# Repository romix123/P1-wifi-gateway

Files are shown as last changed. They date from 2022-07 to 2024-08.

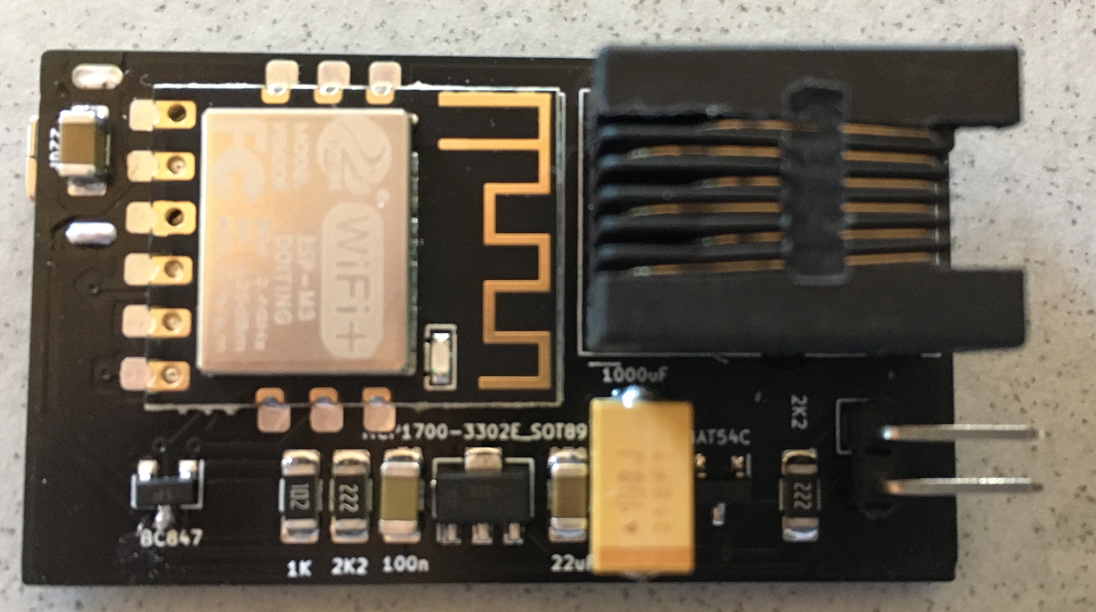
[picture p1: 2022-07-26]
hardware/P1-2022v2top.jpg

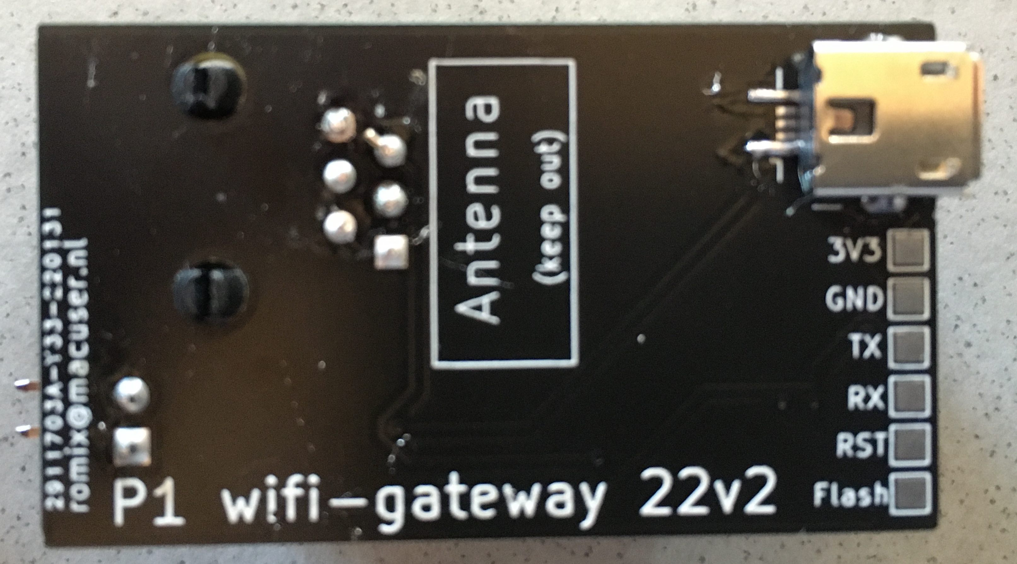
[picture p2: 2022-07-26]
hardware/P1-2022v2bot.jpg

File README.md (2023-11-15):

  P1 wifi gateway 2022
  
  Deze software brengt verschillende componenten bij elkaar in een handzaam pakket.
  
  De software draait op een ESP8285 of ESP8266 en heeft een bescheiden voetafdruk.
  
  De data processing is gebaseerd op: http://domoticx.com/p1-poort-slimme-meter-data-naar-domoticz-esp8266/
  De captive portal is gebaseerd op een van de ESP8266 voorbeelden, de OTA eenheid eveneens.
  
  De module levert data aan een host via JSON of MQTT messages, maar kan ook via de webinterface van de module of via telnet worden uitgelezen
  
  De module zal bij opstarten eerst de buffercondensator laden. 
  Vervolgens knippert hij 2x en zal eerst proberen te koppelen aan je wifi netwerk. Gedurende dat proces zal de LED knipperen
  met een periode van 0.5 Hz.
  Wanneer geen verbinding kan worden gemaakt start de modiule een Access point onder de naam P1_Setup
  Verbind met dit netwerk en surf naar 192.168.4.1
  
  Het menuscherm van de module verschijnt dan. Vul daar SSID en wachtwoord van je wifi netwerk in. 
  Daaronder vul je gegevens van de ontvangede server in (IP en poortnummer). Dit kan je DOmotociz server zijn
  In dat geval moet je ook het IDx dat Domoticz maakt voor een Gas device en een Energy device invoeren.
  Tenslotte geef je aan per hoeveel seconde je data naar de server wilt laten sturen.
  DSMR4 meters hanteren een meetinterval van 10 sec. SMR5 meters leveren iedere seconde data. Dat lijkt me wat veel en 
  kost de module ook veel stroom waardoor het maar de vraag is of hij parasitair (door de meter gevoed) kan werken.
  Ik raad een interval van 15 sec of hoger aan. Het interval dat je hier invoert zal niet altijd synchroon lopen met
  het data interval van de meter, ga er dus niet van uit dat je exact iedere x seconden een meetwaarde ziet in DOmoticz. 
  Tussen metingen 'slaapt' de module (de modem wordt afgeschakeld waardoor het stroomverbruik van zo'n 70mA terugvalt naar 15 mA). 
  Dit geeft de bufferelco tijd om op te laden voor de stroompiekjes die de wifi zender van de module produceert 
  (en het bespaart hoe dan ook wat stroom (die weliswaar door je energieleverancier wordt betaald, maar toch). Alle kleine 
  beetjes helpen..
 
   informatie, vragen, suggesties ed richten aan ronaldleenes@icloud.com
   
   default adminpassword: adminpwd
   
   Zie http://esp8266thingies.nl voor meer informatie over de module en
   http://www.esp8266thingies.nl/wp/forum-2/ voor het disussieforum

 @file P1WG_IDE_2.ino
 @author Ronald Leenes
 @date 22.09.2023
 @version 1.1e 
   
	1.1.e: fixed passwd length related issues (adminpass, SSID, MQTT), worked on wifi persistance, 
			disabled wifi powermanagment, removed multilingual support for now
    1.1d: moved codebase to IDE 2.2, small fixes, added webdebug 

   1.1adc: implemented extensive logging
   			updated Swedish version to align with Dutch version (German and French versions lack security features on setup/update)
   1.1aa: bug fixes
   1.1: implemented graphs
   		fixed reporting tariffIndicatorElectricity
   
   ud: fixed refreshheaders
   ua: fixed setup field issue  
   u: - added password protection for Setup and Update Firmware menus. On first boot of version 1.0u, go to Setup menu 
        within 60 seconds to bypass password protection.
      - added out of the box support for Home Assistant "DSMR Reader" integration. Use 'dsmr' as MQTT prefix and data will
        automatically be delivered in "DSMR Reader" format to the MQTT broker.
      - fixed MQTT reconnect, it is now non-blocking.
      - fixed hardboot daycounters reset
      - fixed sending empty MQTT messages
      - overall improved stability
      
   t: improvements on powermanagement, overall (minor) cleanup
   ta: fix for Telnet reporting
 		added French localisation
   
   s: added German localisation
         Added mqtt output for Swedish specific OBIS codes
         
   r: speed improvements and streamlining of the parser
       localisations for: NL, SE
       
   q: added daily values
   p: incorporated equipmentID in mqtt set
   o: fixed gas output, fixed mqtt reconnect
   n: empty call to SetupSave now redirects to main menu instead of resetting settings ;-)
       fixed kWh/Wh inversion
   m: setupsave fix, relocate to p1wifi.local na 60 sec 
       mqtt - kw/W fix
   l: wifireconnect after wifi loss
   k: fixed big BUG, softAP would not produce accessible webserver.
   j: raw data on port 23
       major code rewrite
       implemented data reporting methods: 
         parsed data: json, mqtt, p1wifi.local/P1
         raw data: telnet on port 23, p1wifi.local/Data
         
   i:  extended max line length for TD210-D meters, which have a really loong 1-0:99.97.0 line
   h:  extended mqtt set with instant powers, voltages, actual tarif group. power outages, power drops
   g: fixed mqtt
   
   Generic ESP8285 module 
	Flash Size: 2mb (FS: 128Kb, OTA: –960Kb) 
   
   needed files: 
   this one (obv), 
   CRC16.h
   JSON.ino
   MQTT.ino
   TELNET.ino
   debug.ino
   decoder.ino
   functions.ino
   graph.ino
   webserver.ino
   webserverNL.ino
   wifi.ino

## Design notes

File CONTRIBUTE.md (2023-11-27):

# Install IDE
The P1-wifi-gateway can be built with either PlatformIO or Arduino 2.

## PlatformIO

### Installation
https://docs.platformio.org/en/latest/integration/ide/pioide.html
- VSCode
- CLion (IntelliJ)
- Commandline

### Configuration
Within platformIO all the configuration is stored within `platform.ini`. Therefore, no additional steps are needed before the actual build.

### Build
 - VSCode: Hit the `build` button
 - CLion: Hit the `build` button
 - Commandline: `platformio run --environment espmxdevkit`

The build is placed in .pio/build/espmxdevkit/firmware.bin

### Arduino 2

### Installation
https://www.arduino.cc/en/software

### Configuration
#### Add Board manager
In the preferences of Arduino IDE add the following board manager url

> https://arduino.esp8266.com/stable/package_esp8266com_index.json

### Install the ESP8266 board
On the left panel in the "Board manager" install

- `esp866` by ESP8266 community | current version 3.1.2

### Install the required libraries

- `Time` by Michael Margolis | version 1.6.1 (search for TimeLib)
- `MyAlarm` by z01ne | version 1.1.2
- `PubSubClient` by Nick O'Leary | version 2.8

### Select the correct board
Search for `DOIT ESP-Mx DevKit (ESP8285)`

### Build
Click `Sketch > verify/compile`. The binary is placed in the temporary folder

- Linux on `/tmp/arduino/sketches/`
- On a Mac use the 'Export compile binary' option in the Sketch menu.
 	the binary will be placed in the build directory in your sketch folder
- Windows on ???

# Test
- Commandline: `platformio test --environment test`

# Upload the new firmware
By default, the P1-wifi-gateway cannot be connected via USB. Therefore, the only option to install the new firmware is by uploading the binary in the Webinterface.

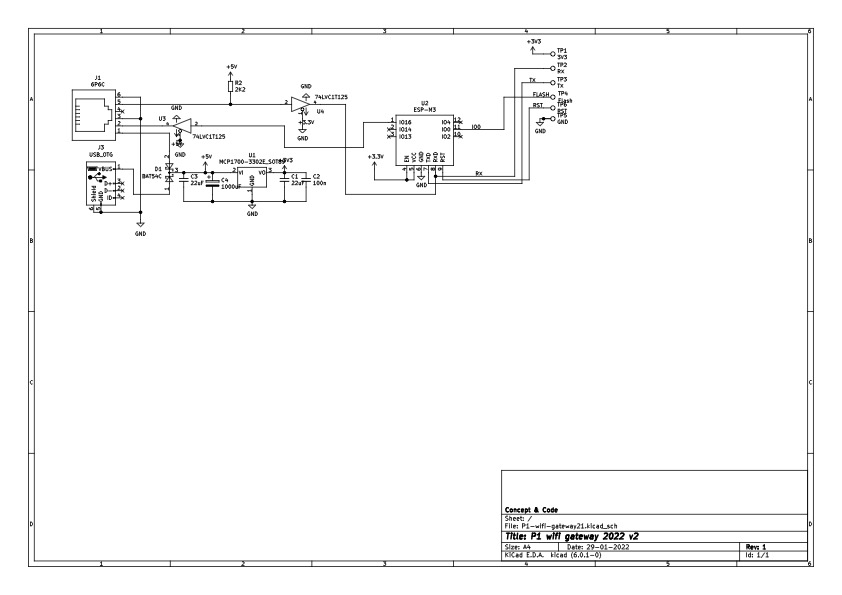
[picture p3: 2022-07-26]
hardware/P1-2022v2schema.jpg

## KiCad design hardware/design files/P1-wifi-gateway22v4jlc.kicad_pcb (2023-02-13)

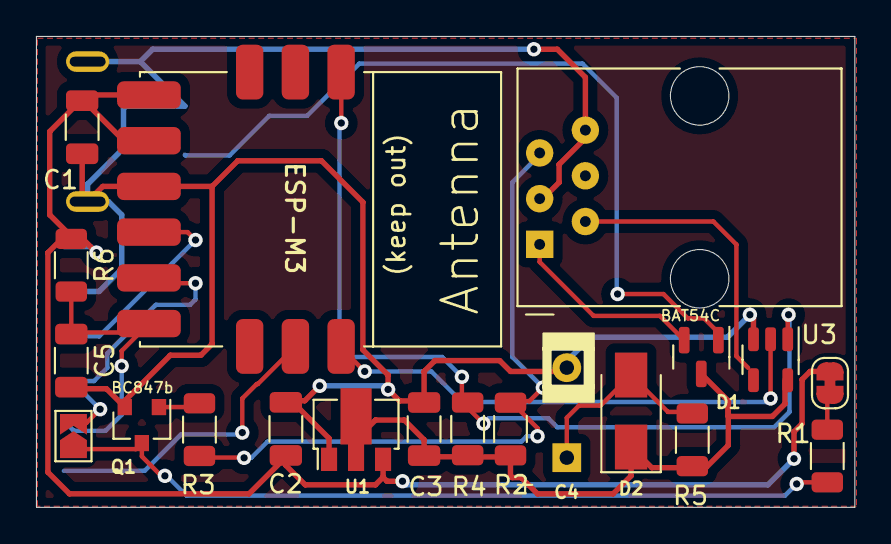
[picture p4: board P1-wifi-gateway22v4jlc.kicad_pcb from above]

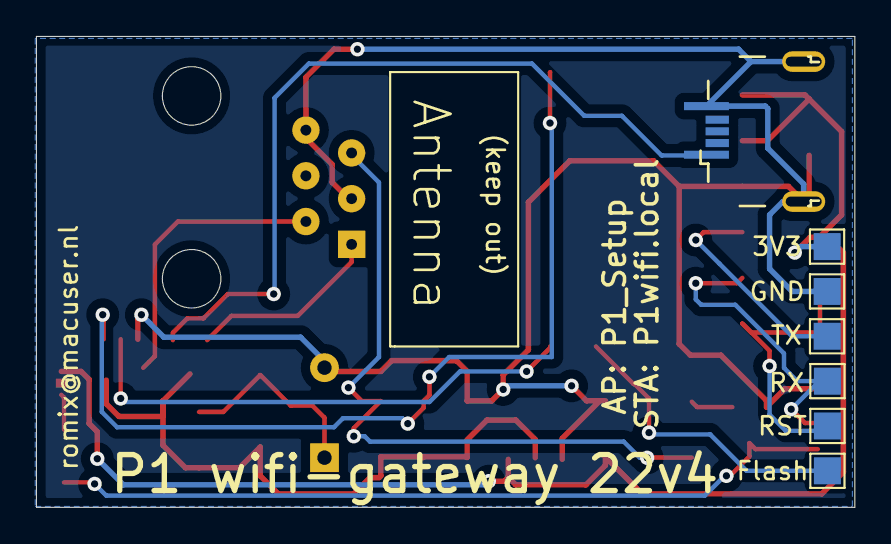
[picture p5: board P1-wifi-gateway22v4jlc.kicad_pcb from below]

Board: 2 copper layers, 45.5 x 26.2 mm, 27 parts (7 on the bottom side), 17 nets.

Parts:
C1: 100n; C_1206_3216Metric
C2: 10u; C_1206_3216Metric
C3, C5: 22uF; C_1206_3216Metric
C4: 3300uF; CP_Radial_D8.0mm_P5.00mm
D1: BAT54C; SOT-23
D2: SS14; D_SMA
J1: 6P6C; RJ12_Amphenol_54601
J3: USB_OTG; USB_Micro-B_Ali_power_only
JP1: SolderJumper_2_Bridged; SolderJumper-2_P1.3mm_Bridged_RoundedPad1.0x1.5mm
JP2: SolderJumper_2_Open; SolderJumper-2_P1.3mm_Open_TrianglePad1.0x1.5mm
Q1: BC847b; SOT-23
R1, R2: 2K2; R_1206_3216Metric
R3: 1K; R_1206_3216Metric
R4: 10k; R_1206_3216Metric
R5: 52.3; R_1206_3216Metric
R6: 100k; R_1206_3216Metric
TP1: 3V3; TestPoint_Pad_1.5x1.5mm
TP2: RX; TestPoint_Pad_1.5x1.5mm
TP3: TX; TestPoint_Pad_1.5x1.5mm
TP4: Flash; TestPoint_Pad_1.5x1.5mm
TP5: GND; TestPoint_Pad_1.5x1.5mm
TP6: RST; TestPoint_Pad_1.5x1.5mm
U1: ME6249A33PG; SOT-89-3
U2: ESP-M3
U3: 74AHCT1G125; SOT-23-5

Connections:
+3V3: C1.1, C2.1, JP1.2 (B), R6.1, TP1.1, U1.3 (VO), U2.4 (EN), U2.5 (VCC)
+5V: C3.1, D1.3, D2.1 (K), R2.1, R4.1, R5.1, U1.2 (VI), U3.5 (VCC)
/FLASH: TP4.1, U2.11 (IO0)
/RST: C5.1, R6.2, TP6.1, U2.9 (RST)
/RX: JP2.2 (B), TP2.1, U2.8 (RXD)
/TX: TP3.1, U2.7 (TXD)
GND: C1.2, C2.2, C3.2, C4.2, C5.2, J1.3, J1.6, J3.5 (GND), J3.6 (Shield), Q1.2 (E), TP5.1, U1.1 (GND), U2.6 (GND), U3.3 (GND)
unnamed: C4.1, D2.2 (A), R5.2
unnamed: D1.1, J3.1 (VBUS)
unnamed: D1.2, J1.1
unnamed: J1.2, U3.4
unnamed: J1.5, R2.2, R3.2
unnamed: JP1.1 (A), R1.1
unnamed: JP2.1 (A), Q1.3 (C), R1.2
unnamed: Q1.1 (B), R3.1
unnamed: R4.2, U2.1 (IO16), U3.1
unnamed: U2.12 (IO4), U3.2

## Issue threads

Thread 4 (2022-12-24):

Send interval not stored

emarvegt, 2022-12-24:
The measuring interval is not stored: when entering a value in the setup, saving and waiting for the restart, the value is not displayed and the actual send interval is 1s, as seen by the MQTT destination receiving all values every second.
In addition, the ESP webserver and data transmission stop working after a few hours and requiring a reboot, which may be related (some overflow or out of memory due to the frequent measuring/sending?).

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

romix123, 2022-12-25:
Ben er mee bezig.
Er komt een grote update deze week.

Verstuurd vanaf mijn iPad

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

emarvegt, 2023-01-03:
De send interval lijkt nog steeds niet opgeslagen te worden in versie s. Bovendien wordt nu de opgeslagen SSID afgekapt na 8 karakters, dus kan hij geen verbinding maken met mijn netwerk met 16 of meer karakters.

Closed 2023-01-15.

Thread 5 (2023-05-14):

Single phase meter Iskra 550A no meter data

HarryHase4, 2023-05-14:
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

The power values are missing.
Im'not a coder and i can not compile it myself, to much errors ;)

HarryHase4, 2023-05-15:
I found an older fork, which i can compile, there i made a "ugly hack" in the decoder.

          if (strncmp(telegram, "1-0:2.7.0", strlen("1-0:2.7.0")) == 0)
          getValue(actualElectricityPowerReturned, telegram, len, '(', '*');

          if (strncmp(telegram, "1-0:22.7.0", strlen("1-0:22.7.0")) == 0)
          getValue(actualElectricityPowerReturned, telegram, len, '(', '*');

I don't understand why 1-0:2.7.0 is not working

romix123, 2023-05-15:
I will fix this soonVerstuurd vanaf mijn iPadOp 15 mei 2023 om 16:03 heeft HarryHase4 ***@***.***> het volgende geschreven:
I found an older fork, which i can compile, there i made a "ugly hack" in the decoder.
      if (strncmp(telegram, "1-0:2.7.0", strlen("1-0:2.7.0")) == 0)
      getValue(actualElectricityPowerReturned, telegram, len, '(', '*');

      if (strncmp(telegram, "1-0:22.7.0", strlen("1-0:22.7.0")) == 0)
      getValue(actualElectricityPowerReturned, telegram, len, '(', '*');

I don't understand why 1-0:2.7.0 is not working

—Reply to this email directly, view it on GitHub, or unsubscribe.You are receiving this because you are subscribed to this thread.Message ID: ***@***.***>

romix123, 2023-05-16:
The issue is that your meter terminates the values with the units (e.g. kWh) instead of with * followed by unit (eg *kWh). I will make a fix later this week

romix123, 2023-05-20:
Firmware P1WG2022v1.1be.NL.esp8285.bin
should fix this issue

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

HarryHase4, 2023-05-20:
can not find  P1WG2022v1.1be.NL.esp8285.bin (and the code for it) ..

romix123, 2023-05-20:
forgot to push
https://github.com/romix123/P1-wifi-gateway/tree/main/firmware

HarryHase4, 2023-05-20:
Not fixes, the star was mit the Problem, please See my comments.
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

romix123, 2023-05-21:
There is something weird with the ISKRA protocol. Will fix it later this week. Can you send me another dump of
p1wifi.local/Raw

and a screenshot?

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

HarryHase4, 2023-05-21:
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

`/ISK5\2M550E-1011 1-3:0.2.8(50) 0-0:1.0.0(230521133516S) 0-0:96.1.1(4530303333303036383737333434363137) 1-0:1.8.1(003211.396*kWh) 1-0:1.8.2(002025.059*kWh) 1-0:2.8.1(004697.961*kWh) 1-0:2.8.2(010993.348*kWh) 0-0:96.14.0(0001) 1-0:1.7.0(00.000*kW) 1-0:2.7.0(01.376*kW) 0-0:96.7.21(00010) 0-0:96.7.9(00006) 1-0:99.97.0(4)(0-0:96.7.19)(190111133452W)(0000002779*s)(190307113415W)(0000004950*s)(210727172710S)(0000003977*s)(210727183630S)(0000001107*s) 1-0:32.32.0(00094) 1-0:32.36.0(00008) 0-0:96.13.0() 1-0:32.7.0(241.8*V) 1-0:31.7.0(005*A) 1-0:21.7.0(00.000*kW) 1-0:22.7.0(01.364*kW) 0-1:24.1.0(003) 0-1:96.1.0(4730303332353635353039343630383137) 0-1:24.2.1(230521133505S)(03199.256*m3) !1DC4`

HarryHase4, 2023-05-21:
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

`/ISK5\2M550E-1011 1-3:0.2.8(50) 0-0:1.0.0(230521133516S) 0-0:96.1.1(453030333330303638xxxxxx) 1-0:1.8.1(003211.396*kWh) 1-0:1.8.2(002025.059*kWh) 1-0:2.8.1(004697.961*kWh) 1-0:2.8.2(010993.348*kWh) 0-0:96.14.0(0001) 1-0:1.7.0(00.000*kW) 1-0:2.7.0(01.376*kW) 0-0:96.7.21(00010) 0-0:96.7.9(00006) 1-0:99.97.0(4)(0-0:96.7.19)(190111133452W)(0000002779*s)(190307113415W)(0000004950*s)(210727172710S)(0000003977*s)(210727183630S)(0000001107*s) 1-0:32.32.0(00094) 1-0:32.36.0(00008) 0-0:96.13.0() 1-0:32.7.0(241.8*V) 1-0:31.7.0(005*A) 1-0:21.7.0(00.000*kW) 1-0:22.7.0(01.364*kW) 0-1:24.1.0(003) 0-1:96.1.0(47303033323xxxxx) 0-1:24.2.1(230521133505S)(03199.256*m3) !1DC4`

romix123, 2023-05-21:
How about this

HarryHase4, 2023-05-21:
no Actueel verbruik

`1-0:2.7.0(01.376*kW)
1-0:22.7.0(01.364*kW)
`

HarryHase4, 2023-05-23:
I can test it on next monday ..

emarvegt, 2023-07-25:
Was this ever solved? I have the same issue, also with an ISKRA 550, but I think in both cases it's only the return value that is missing. The PowerDelivered value works correctly. It is 0 when my solar panels are able to supply the energy the house currently needs, so 0 is what is drawn from the grid at that moment.
The PowerReturned value shows nothing, but should show the excess solar that isn't consumed by the house and flows back into the grid. And I think I can see it in the datagram:

`/ISK5\2M550T-1012 1-3:0.2.8(50) 0-0:1.0.0(230725165848S) 0-0:96.1.1(4530303434303036383432393836313137) 1-0:1.8.1(010022.217*kWh) 1-0:1.8.2(007192.203*kWh) 1-0:2.8.1(003940.472*kWh) 1-0:2.8.2(008902.806*kWh) 0-0:96.14.0(0002) 1-0:1.7.0(00.000*kW) 1-0:2.7.0(01.223*kW) 0-0:96.7.21(00005) 0-0:96.7.9(00002) 1-0:99.97.0() 1-0:32.32.0(00013) 1-0:52.32.0(00011) 1-0:72.32.0(00011) 1-0:32.36.0(00001) 1-0:52.36.0(00001) 1-0:72.36.0(00001) 0-0:96.13.0() 1-0:32.7.0(237.4*V) 1-0:52.7.0(234.0*V) 1-0:72.7.0(236.3*V) 1-0:31.7.0(006*A) 1-0:51.7.0(001*A) 1-0:71.7.0(001*A) 1-0:21.7.0(00.000*kW) 1-0:41.7.0(00.120*kW) 1-0:61.7.0(00.180*kW) 1-0:22.7.0(01.513*kW) 1-0:42.7.0(00.000*kW) 1-0:62.7.0(00.000*kW) 0-1:24.1.0(003) 0-1:96.1.0(4730303339303031383035373739393138) 0-1:24.2.1(230725165507S)(08392.804*m3) !9F4F`

romix123, 2023-07-26:
I don’t remember whether this was fixed. I will take another look at it.

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

artenverho, 2023-10-02:
Hi , I am having the same issue with newest firmware version 1.1c. I seem to be able to access it through fine but the readout of the iskra is very erratic and often give 0 values. Is there an easy fix?

romix123, 2023-10-03:
Can you send me some output obtained with p1wifi.local/DataVerstuurd vanaf mijn iPadOp 2 okt. 2023 om 21:18 heeft artenverho ***@***.***> het volgende geschreven:
Hi , I am having the same issue with newest firmware version 1.1c. I seem to be able to access it through fine but the readout of the iskra is very erratic and often give 0 values. Is there an easy fix?

—Reply to this email directly, view it on GitHub, or unsubscribe.You are receiving this because you commented.Message ID: ***@***.***>

artenverho, 2023-10-03:
Data below is from when it works. I will try to also catch it when it is not reporting correctly. I also noticed it was showing online for only 8 hours. So it might also be a power/reset issue?

```
/ISK5\2M550T-1012 1-3:0.2.8(50) 0-0:1.0.0(231003211953S) 0-0:96.1.1(4530303434303036383631393137393137) 1-0:1.8.1(010440.983*kWh) 1-0:1.8.2(008309.479*kWh) 1-0:2.8.1(004548.906*kWh) 1-0:2.8.2(010594.587*kWh) 0-0:96.14.0(0002) 1-0:1.7.0(00.247*kW) 1-0:2.7.0(00.000*kW) 0-0:96.7.21(00006) 0-0:96.7.9(00006) 1-0:99.97.0(4)(0-0:96.7.19)(180927121812S)(0000000378*s)(181115132909W)(0001136092*s)(181116110923W)(0000077917*s)(190114104207W)(0000000284*s) 1-0:32.32.0(00009) 1-0:52.32.0(00007) 1-0:72.32.0(00008) 1-0:32.36.0(00003) 1-0:52.36.0(00003) 1-0:72.36.0(00003) 0-0:96.13.0() 1-0:32.7.0(233.0*V) 1-0:52.7.0(234.3*V) 1-0:72.7.0(235.3*V) 1-0:31.7.0(000*A) 1-0:51.7.0(001*A) 1-0:71.7.0(000*A) 1-0:21.7.0(00.091*kW) 1-0:41.7.0(00.097*kW) 1-0:61.7.0(00.061*kW) 1-0:22.7.0(00.000*kW) 1-0:42.7.0(00.000*kW) 1-0:62.7.0(00.000*kW) !3C61
```

artenverho, 2023-10-06:
So it seems it has become very difficult for me to debug the current situation:

I checked domoticz and no data was reported for more than 30 hours. Then I tried to access the p1 gateway through a webbrowser. The page took a while to load and as soon as it did the uptime showed 0 days 0 hours 0 min, but reporting to domoticz did startup  correctly again. Perhaps this is a power issue? I am surprised however that it is able to reset as soon as I try to access it via the webserver. I will try to run it with power for a while and see if that fixes the issue.

romix123, 2023-10-09:
I am working on the code. This issue is still on my stack.
I may revamp the entire parsing routine.

artenverho, 2023-10-10:
Let me know if I can provide logs, etc.. I tried whether running it from external power would solve the issue, but this had no effect.

romix123, 2023-10-16:
I am working on a telnet debug port. I will uplaod a debug version on Github later this week

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

emarvegt, 2024-08-21:
I can confirm this is fixed with version 1.2ba
(the firmware update messed up most settings so I had to reconfigure those, but then it worked and the power values are showing up).

emarvegt, 2024-08-27:
Unfortunately the ‘report in W’ does not switch all value ranges in the same way, it seems. And the firmware seems less stable too.

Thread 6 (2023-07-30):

reconnecting to wifi after a power cut

Leon3310, 2023-07-30:
Hello,

I have been using "P1-wifi gateway 2022"  from Belgium for many months. It works very well. I just had a few problems during my holidays. The power was cut off for 1 hour because of work being carried out in the street while I was away.

The P1 didn't reconnect to the wifi when the power came back on. I suppose my wifi router takes a bit longer to start up than the P1.

Because of this, I've lost a few days of history.

When I'm at home, I just disconnect and reconnect and everything works again.

Is it possible to do anything about this kind of problem?

For example, trying to reconnect to the wifi with a delay?
An option to restart at a certain time (every day)?
...

Thank you very much for your work

romix123, 2023-08-20:
I will see what I can do.Verstuurd vanaf mijn iPadOp 30 jul. 2023 om 09:27 heeft Leon3310 ***@***.***> het volgende geschreven:
Hello,
I have been using "P1-wifi gateway 2022"  from Belgium for many months. It works very well. I just had a few problems during my holidays. The power was cut off for 1 hour because of work being carried out in the street while I was away.
The P1 didn't reconnect to the wifi when the power came back on. I suppose my wifi router takes a bit longer to start up than the P1.
Because of this, I've lost a few days of history.
When I'm at home, I just disconnect and reconnect and everything works again.
Is it possible to do anything about this kind of problem?
For example, trying to reconnect to the wifi with a delay?
An option to restart at a certain time (every day)?
...
Thank you very much for your work

—Reply to this email directly, view it on GitHub, or unsubscribe.You are receiving this because you are subscribed to this thread.Message ID: ***@***.***>

Closed 2024-12-12.

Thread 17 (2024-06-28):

Incorrect: INVALID CRC FOUND

ronnievdc, 2024-06-28:
I'm researching why i'm getting multiple messages of "INVALID CRC FOUND"

Here is some logging when i constantly input the same telegram:
```
STATE: 2 >> !6DE3
messageCRC 6DE3
VALID CRC FOUND!

STATE: 2 >> !6DE3
messageCRC 6DE3��
VALID CRC FOUND!

STATE: 2 >> !6DE3
messageCRC 6DE3u
VALID CRC FOUND!

STATE: 2 >> !6DE3
messageCRC 6DE3=�
VALID CRC FOUND!

STATE: 2 >> !6DE3
messageCRC 6DE3��
VALID CRC FOUND!

STATE: 2 >> !6DE3
messageCRC 6DE3�Q
VALID CRC FOUND!

STATE: 2 >> !6DE3
messageCRC 6DE3��
VALID CRC FOUND!

STATE: 2 >> !6DE3
messageCRC 6DE3@
VALID CRC FOUND!

STATE: 2 >> !6DE3
messageCRC 6DE3;�
VALID CRC FOUND!

STATE: 2 >> !6DE3
messageCRC 6DE3d.
===INVALID CRC FOUND!===
```

I suspect the `messageCRC` is not  NULL terminated, therefore `strtoul` adds the fifth character when its in range of `0-9A-F` and therefor the check fails.

```cpp
char messageCRC[4];
strncpy(messageCRC, telegram + endChar + 1, 4);
validCRCFound = (strtoul(messageCRC, NULL, 16) == currentCRC);
```

Closed 2024-06-30.

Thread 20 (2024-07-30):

Full filesystem due LittleFS

ronnievdc, 2024-07-30:
From https://arduino-esp8266.readthedocs.io/en/latest/filesystem.html

> LittleFS is recently added and focuses on higher performance and directory support, but has higher filesystem and per-file overhead (4K minimum vs. SPIFFS’ 256 byte minimum file allocation unit).

The logging.h module can create up to 57 logfiles if i'm correct. Each logfile taking at least 4KB of space, the filesystem can should need at least 228KB. Since it only has 128KB we can Revert back to SPIFFS or save more types of data into one file. For example

```
/HourE1.log
/HourE2.log
/HourG.log
/HourR1.log
/HourR2.log
/HourTE.log
/HourTR.log
```

could be saved into one file `Hour.log` with all the values of that hour. This could also make the logging code easier and less Write instructions to the flashdrive.

romix123, 2024-08-01:
I am in favour of completely revamping the local data storage.
The current configuration was made to allow for rapid graph production at the expense of storage efficiency.
LittleFS was used instead of SPIFFS because SPIFSS stopped working at random moments.
There still are many errors in the graph functions anyway.

Let's discuss requirements for graphs.
Storing all core data (as listed above) in a single entry each hour and retaining the last one of the day for up to 13 months would allow all sorts of graphs to be produced.

ronnievdc, 2024-08-01:
Ill suggest 3 files
 - today.log (values for each hour today, starting at <Dayrotation>)
 - yesterday.log (values for each hour yesterday, at <Dayrotation> today.log is renamed to yesterday.log)
 - <year>.log (values for each day of the year, starting at 1-1-xxxx, hour of logging: <Dayrotation>). Each year a new file is created.

Dayrotation: time should be configurable to adjust for different timezones not counting DaylightSavingTime. Range: -12 to 12 hours.

Formatting of the line (i prefer Binary over ASCII):
```cpp
struct StatisticsLineV1 {
  uint8_t version;     // starting with 1
  uint64_t timestamp;  // unix timestamp as returned by the Time now() method
  uint32_t energy_delivered_tariff1;  // total value in Watt (1000 x P1-value)
  uint32_t energy_delivered_tariff2;
  uint32_t energy_returned_tariff1;
  uint32_t energy_returned_tariff2;
  uint32_t gas_delivered;  // total value in dm3 (1000 x P1-value)
}
```

The version could be increased when we need the change the format of the line. Then its possible to check the first 8 bits to see which parser is needed for the rest of the line.

I think storing only the total values is needed. The difference can be calculated by comparing to the previous record.

ronnievdc, 2024-08-01:
And some proposed class setup

```cpp
// Handling saving data to the filesystem and retrieving data from the filesystem
class Statistics {
 public:
  explicit Statistics(FS &fileSystem) : mFileSystem(fileSystem) {}
  // rename today.log -> yesterday.log
  void rotateDay() {}
  // saves values in today.log
  void saveHour(const DSMRData &data) {}
  // saves values in <year>.log
  void saveday(const DSMRData &data) {}
  // helper method to create from/to timestamps
  static inline uint64_t createTime(uint8_t year, uint8_t month, uint8_t day) {
    tmElements_t tmElements = {0, 0, 0, 1, day, month, CalendarYrToTm(year)};
    return makeTime(tmElements);
  }
  // streams values of yesterday.log + today.log
  void getHours(const StatisticsStream &stream) {}
  // streams values of <year>.log in between from timestamp and to timestamp
  void getDays(const StatisticsStream &stream, const uint64_t from,
               const uint64_t to) {}
  // streams values of <year>.log in between from timestamp and to timestamp
  // but only 1st entry of the week
  void getWeeks(const StatisticsStream &stream, const uint64_t from,
                const uint64_t to) {}
  // streams values of <year>.log in between from timestamp and to timestamp
  // only 1st entry of the month
  void getMonths(const StatisticsStream &stream, const uint64_t from,
                const uint64_t to) {}

 private:
  FS &mFileSystem;
};

// Interface class handle lines from the logfiles
// I chose for streams because logfiles can become big
// therefore handling line by line seems a good idea to manage resources.
class StatisticsStream {
 public:
  StatisticsStream() {}
  virtual void parseLine(const StatisticsLineV1 &line) = 0;
};

// Sample class that prints the energy_delivered_tariff1 per line to the Serial port.
class StatisticsStreamSerial : public StatisticsStream {
 public:
  explicit StatisticsStreamSerial(HardwareSerial &serial) : mSerial(serial) {}
  void parseLine(const StatisticsLineV1 &line) override {
    mSerial.println(line.energy_delivered_tariff1);
  }

 private:
  HardwareSerial &mSerial;
};

///////////////////
// Example usage //
///////////////////
Statistics s(FST);
s.rotateDay();
s.saveHour(dsmrData);
s.saveday(dsmrData);

StatisticsStreamSerial ss(Serial);
s.getDays(ss, s.createTime(2024, 1, 1), s.createTime(2025, 2, 1));
s.getWeeks(ss, s.createTime(2024, 1, 1), s.createTime(2025, 12, 1));
s.getMonths(ss, s.createTime(2000, 1, 1), s.createTime(2030, 1, 1));
```

romix123, 2024-08-12:
cool

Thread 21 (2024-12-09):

Are there plans to add read of connecter water meter

PeterSchops, 2024-12-09:
In Belgium next to the gas meter also a water meter is connected. So it would be nice to also read out these values.

romix123, 2024-12-10:
If you can dig up info about the obis codes used for water, then, no problem, I csn add water.Verstuurd vanaf mijn iPadOp 10 dec 2024 om 00:15 heeft PeterSchops ***@***.***> het volgende geschreven:
In Belgium next to the gas meter also a water meter is connected. So it would be nice to also read out these values.

—Reply to this email directly, view it on GitHub, or unsubscribe.You are receiving this because you are subscribed to this thread.Message ID: ***@***.***>

PeterSchops, 2024-12-10:
After some searching I managed to find the information on the internet. It seems to be very similar to the gas readout, so it is probably not very hard to add it. But it needs to be added in multiple places.

ObisId 0-2:24.2.1

.7.0(002.31*A)
0-0:96.3.10(1)
0-0:17.0.0(999.9*kW)
1-0:31.4.0(999*A)
0-0:96.13.0()
0-1:24.1.0(003)
0-1:96.1.1(37464C4F32313232313439303732)
0-1:24.4.0(1)
0-1:24.2.3(221028214000S)(00032.932*m3)
0-2:24.1.0(007)
0-2:96.1.1(3853455430303030323136343232)
0-2:24.2.1(221028213843S)(00004.332*m3)
!4394
/FLU5\253770234_A

romix123, 2024-12-11:
I can add the water meter. That is not too hard. The trouble is that the Belgian obis codes are a bit messy and that it is tricky to detect which is gas and which water (0-2.24.2.3 and 0-2.24.2.1)

For gas it was
In NL the OBIS reference is: 0-1:24.2.1
In B the OBIS reference is: 0-1:24.2.3

but I have found a ciomment that BE is/has switched to the NL code. From your data, I assume 24.2.1 is water, not gas

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

PeterSchops, 2024-12-11:
The .1 or .3 at the end seems to refer to the measurement type (1: base value, 3: non-temperature compensated)

0-1:24.1.0(003)                                                      gas-meter mbus id
0-1:96.1.1(37464C4F32313232313439303732)   gas-meter id DIN43863-5 (fluvius) format
0-1:24.4.0(1)
0-1:24.2.3(221028214000S)(00032.932m3)         gas-meter reported value (.3 is non-temperature compensated value)
0-2:24.1.0(007)                                                      water-meter mbus id
0-2:96.1.1(3853455430303030323136343232)    water-meter id DIN43863-5 (fluvius) format
0-2:24.2.1(221028213843S)(00004.332*m3)        water-meter reported value (.1 is base value)

When I look to implementation somewhere else, I saw that for gas it was favoring the .1 measurement. But when no data is found for .1 it would take the .3 value.
https://github.com/plan-d-io/P1-dongle/blob/main/dsmrTelegram.ino   (line 443)

PeterSchops, 2025-01-08:
I forked a fork of your project, and added the readout of water.
https://github.com/PeterSchops/P1-wifi-gateway

Adding the readout itself was not so hard in the end.

For the moment my hardware is working without the buffer, so I need to invert the communication. So my version will not run on your hardware. But I plan to still fix that.

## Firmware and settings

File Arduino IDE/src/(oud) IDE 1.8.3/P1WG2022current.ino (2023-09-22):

 /*
 * Copyright (c) 2023 Ronald Leenes
 *
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
 */

/**
 * @file P1WG2022current.ino
 * @author Ronald Leenes
 * @date 22.09.2023
 * @version 1.1c 
 *
 * @brief This file contains the main file for the P1 wifi gatewway
 *
 * @see http://esp8266thingies.nl
 */
 
/*
 * P1 wifi gateway 2022
 * 
 * Deze software brengt verschillende componenten bij elkaar in een handzaam pakket.
 * 
 * De software draait op een ESP8285 of ESP8266 en heeft een bescheiden voetafdruk.
 * 
 * De data processing is gebaseerd op: http://domoticx.com/p1-poort-slimme-meter-data-naar-domoticz-esp8266/
 * De captive portal is gebaseerd op een van de ESP8266 voorbeelden, de OTA eenheid eveneens.
 * 
 * De module levert data aan een host via JSON of MQTT messages, maar kan ook via de webinterface van de module of via telnet worden uitgelezen
 * 
 * De module zal bij opstarten eerst de buffercondensator laden. 
 * Vervolgens knippert hij 2x en zal eerst proberen te koppelen aan je wifi netwerk. Gedurende dat proces zal de LED knipperen
 * met een periode van 0.5 Hz.
 * Wanneer geen verbinding kan worden gemaakt start de modiule een Access point onder de naam P1_Setup
 * Verbind met dit netwerk en surf naar 192.168.4.1
 * 
 * Het menuscherm van de module verschijnt dan. Vul daar SSID en wachtwoord van je wifi netwerk in. 
 * Daaronder vul je gegevens van de ontvangede server in (IP en poortnummer). Dit kan je DOmotociz server zijn
 * In dat geval moet je ook het IDx dat Domoticz maakt voor een Gas device en een Energy device invoeren.
 * Tenslotte geef je aan per hoeveel seconde je data naar de server wilt laten sturen.
 * DSMR4 meters hanteren een meetinterval van 10 sec. SMR5 meters leveren iedere seconde data. Dat lijkt me wat veel en 
 * kost de module ook veel stroom waardoor het maar de vraag is of hij parasitair (door de meter gevoed) kan werken.
 * Ik raad een interval van 15 sec of hoger aan. Het interval dat je hier invoert zal niet altijd synchroon lopen met
 * het data interval van de meter, ga er dus niet van uit dat je exact iedere x seconden een meetwaarde ziet in DOmoticz. 
 * Tussen metingen 'slaapt' de module (de modem wordt afgeschakeld waardoor het stroomverbruik van zo'n 70mA terugvalt naar 15 mA). 
 * Dit geeft de bufferelco tijd omm op te laden voor de stroompiekjes die de wifi zender van de module produceert 
 * (en het bespaart hoe dan ook wat stroom (die weliswaar door je energieleverancier wordt betaald, maar toch). Alle kleine 
 * beetjes helpen..
 *
 *  informatie, vragen, suggesties ed richten aan romix@macuser.nl 
 *  
 *  
 *    
 *  versie: 1.1c 
 *  datum:  22 Sep 2023
 *  auteur: Ronald Leenes
 *  
 *  1.1c: clean-up. Telnet can now accept 10 sessions at the same time. Restart when max is reached.
 *  1.1bf: kludge to fix empty ret value. Somehow the value is overwritten by something. Relocating defs for actualElectricityPowerDeli and Ret seems to fix it ofr now
 *  1.1bea: extended field length for actualElectricityPowerDeli[12] and actualElectricityPowerRet[12];
 *  1.1be: added support for ISKRA /ISK5\2M550E-1011 (which terminates 1-0.2.7.0 and 1-0:22.7.0 without *, using kW instead) 
 *  1.1bd: added 3 phase consumption in webdashboard
 *          fixe 3 phase voltage in webdashboard
 *  1.1b    cleaning up, bug fixes, cosmetic changes
 *  1.1adc
 *  1.1ad: bug fixes and graph improvements
 *  1.1aa: bug fixes
 *  1.1: implemented graphs
 *  
 *  
 *  ud: fixed refreshheader
 *  ua: fixed setup field issue
 *  u: 
 *    password on Setup and Firmware Update
 *    made mqtt re-connect non-blocking
 *    incorporated "DSMR Reader" mqtt topics 
 *    fixed hardboot daycounters reset
 *    fixed sending empty MQTT messages
 *  
 *  t: improvements on powermanagement, overall (minor) cleanup
 *  ta: fix for Telnet reporting
 *  
 *  s: added German localisation
 *        Added mqtt output for Swedish specific OBIS codes
 *        
 *  r: speed improvements and streamlining of the parser
 *      localisations for: NL, SE
 *      
 *  q: added daily values
 *  p: incorporated equipmentID in mqtt set
 *  o: fixed gas output, fixed mqtt reconnect
 *  n: empty call to SetupSave now redirects to main menu instead of resetting settings ;-)
 *      fixed kWh/Wh inversion
 *  m: setupsave fix, relocate to p1wifi.local na 60 sec 
 *      mqtt - kw/W fix
 *  l: wifireconnect after wifi loss
 *  k: fixed big BUG, softAP would not produce accessible webserver.
 *  j: raw data on port 23
 *      major code rewrite
 *      implemented data reporting methods: 
 *        parsed data: json, mqtt, p1wifi.local/P1
 *        raw data: telnet on port 23, p1wifi.local/Data
 *        
 *  i:  extended max line length for TD210-D meters, which have a really loong 1-0:99.97.0 line
 *  h:  extended mqtt set with instant powers, voltages, actual tarif group. power outages, power drops
 *  g: fixed mqtt
 *  
 *  Generic ESP8285 module 
*   Flash Size: 2mb (FS: 128Kb, OTA: –960Kb) 
*   
*   needed files: 
*   this one (obv), 
*   vars.h            in the process of moving all vars here
*   lang.h
*   CRC16.h
*   JSON.ino
*   MQTT.ino
*   TELNET.ino
*   debug.ino
*   decoder.ino
*   functions.ino
*   graph.ino
*   webserver.ino
*   webserverDE.ino 
*   webserverSE.ino
*   webserverNL.ino
*   wifi.ino
*   
*/

// to do: implement reboot when 5 mins in setup-window


bool zapfiles = false; 

String version = "1.1c – NL";
#define   NEDERLANDS //  SWEDISH //      GERMAN//   FRENCH // 

#define HOSTNAME "p1meter"
#define FSystem 1 // 0= LittleFS 1 = SPIFFS  

#define GRAPH 1
#define V3
#define DEBUG 0//1//0//3//2//1 is on serial only, 2 is serial + telnet, 
#define DEBUG2 0
#define DEBUGT 1

#define ESMR5 1
//#define SLEEP_ENABLED 


const uint32_t  wakeTime = 90000; // stay awake wakeTime millisecs 
const uint32_t  sleepTime = 15000; //sleep sleepTime millisecs

#if DEBUG2 == 1
#define debug2(x) Serial.print(x)
#define debug2ln(x) Serial.println(x)
#else
#define debug2(x)
#define debug2ln(x)
#endif

#if DEBUG == 1
const char* host = "P1test";
#define BLED LED_BUILTIN
#define debug(x) Serial.print(x)
#define debugf(x) Serial.printf(x)
#define debugff(x,y) Serial.printf(x,y)
#define debugfff(x,y,z) Serial.printf(x,y,z)
#define debugln(x) Serial.println(x)
#elif DEBUG == 2
#define BLED LED_BUILTIN
#define debug(x) Serial.print(x);if(telnetConnected)telnet.print(x)
#define debugf(x) Serial.printf(x)
#define debugff(x,y) Serial.printf(x,y)
#define debugfff(x,y,z) Serial.printf(x,y,z)
#define debugln(x) Serial.println(x);if(telnetConnected)telnet.println(x)
#elif DEBUG == 3
const char* host = "P1home";
#define BLED LED_BUILTIN
#define debug(x)
#define debugln(x)
#define debugf(x)
#define debugff(x,y)
#define debugfff(x,y,z)
#else
const char* host = "P1wifi";
#define BLED LED_BUILTIN
#define debug(x)
#define debugln(x)
#define debugf(x)
#define debugff(x,y)
#define debugfff(x,y,z)
#endif

#define errorHalt(msg) {debugln(F(msg)); return;}

#define NUM(off, mult) ((P1timestamp[(off)] - '0') * (mult) )   // macro for getting time out of timestamp, see decoder

#define ToggleLED  digitalWrite(BLED, !digitalRead(BLED));
#define LEDoff  digitalWrite(BLED, HIGH);
#define LEDon   digitalWrite(BLED, LOW);
#define OE  16 //IO16 OE on the 74AHCT1G125 
#define DR  4  //IO4 is Data Request

#include "vars.h"
#include "lang.h"

#include <TZ.h>
#define MYTZ TZ_Europe_Amsterdam
#include <TimeLib.h>
#include <coredecls.h> // settimeofday_cb()
#include <MyAlarm.h>


#include <ESP8266WiFi.h>
#include <ESP8266HTTPClient.h>
#include <WiFiUdp.h>
#include "CRC16.h"

#if GRAPH == 1
//#include "lfs.h"
#if FSystem == 0
#include <LittleFS.h>
#define FST LittleFS
#elif FSystem == 1
#include "FS.h" //SPIFFS
#define FST SPIFFS
#endif
File file;
#endif


// van ESP8266WiFi/examples/WiFiShutdown/WiFiShutdown.ino
#ifndef RTC_config_data_SLOT_WIFI_STATE
#define RTC_config_data_SLOT_WIFI_STATE 33u
#endif
#include <include/WiFiState.h>  // WiFiState structure details
WiFiState WiFistate;



//van captive portal
/*  ============================================================================================================

    Captive Portal based on:
    https://gitlab.com/MrDIYca/code-samples/-/raw/master/esp8266_setup_portal.ino

    For more info, please watch my video at https://youtu.be/1VW-z4ibMXI
    MrDIY.ca
  ============================================================================================================== */
#include <EEPROM.h>
#include <ESP8266WebServer.h>
ESP8266WebServer    server(80);

#include <WiFiClient.h>
#include <ESP8266mDNS.h>

// mqtt stuff . https://github.com/ict-one-nl/P1-Meter-ESP8266-MQTT/blob/master/P1Meter/P1Meter.ino
#include <PubSubClient.h>
WiFiClient espClient;                   // * Initiate WIFI client
PubSubClient mqtt_client(espClient);    // * Initiate MQTT client
bool MQTT_Server_Fail = false;
long nextMQTTreconnectAttempt; 
// end mqtt stuff

//// Raw data server
WiFiServer telnet(port);
WiFiClient telnetClients[MAX_SRV_CLIENTS];

ADC_MODE(ADC_VCC);  // allows you to monitor the internal VCC level;
  



void setup() {
  WiFi.forceSleepBegin(sleepTime * 1000000L); //In uS. Must be same length as your delay
  delay(10); // it doesn't always go to sleep unless you delay(10); yield() wasn't reliable
  delay(sleepTime); //Hang out at 15mA for (sleeptime) seconds
  WiFi.forceSleepWake(); // Wifi on

  pinMode(BLED, OUTPUT);
  Serial.begin(115200);
/* swap serial ports to gpio15(tx) and gpio13(rx)
  delay(500);
  Serial.swap();
  delay(500);
end swap  */ 
  debugln("Serial.begin(115200);");
    
  pinMode(OE, OUTPUT);      //IO16 OE on the 74AHCT1G125
  digitalWrite(OE, HIGH);   //  Put(Keep) OE in Tristate mode
  pinMode(DR, OUTPUT);      //IO4 Data Request
  digitalWrite(DR, LOW);    //  DR low (only goes high when we want to receive data)

  blink(2);
    debugln("Booting");
    debugln("Done with Cap charging … ");
    debugln("Let's go …");
    
  EEPROM.begin(sizeof(struct settings) );
  EEPROM.get( 0, config_data );
  
  if (config_data.dataSet[0] !='j') {
      config_data = (settings) {"n", "orbi","Moesmate","192.168.1.12","8080","1234","1235","sensors/power/p1meter","192.168.1.12","1883", "mqtt_user", "mqtt_passwd", "30", "n","n","n","n","n","adminpwd"};
  }
 
  (config_data.watt[0] =='j') ? reportInDecimals = false : reportInDecimals = true;
  (config_data.domo[0] =='j') ? Json = true : Json = false;
  (config_data.mqtt[0] =='j') ? Mqtt = true : Mqtt = false;
  (config_data.telnet[0] =='j') ? Telnet = true : Telnet = false;
  (config_data.debug[0] =='j') ? MQTT_debug = true : MQTT_debug = false;
  if (strcmp(config_data.mqttTopic, "dsmr") == 0) { // auto detext need to report in 'dsmr reader' mqtt format
    mqtt_dsmr = true;
   // reportInDecimals = true;
  } else {
    mqtt_dsmr = false; 
   // reportInDecimals = false;
  }
   
  debugln("EEprom read: done");
  PrintConfigData();  

  interval = atoi( config_data.interval) * 1000; 
  debug("interval: ");
  debugln(interval);
  
  debugln("Trying to connect to your wifi network:");
  WiFi.mode(WIFI_STA);
  WiFi.begin(config_data.ssid, config_data.password);    
    byte tries = 0;
    while (WiFi.status() != WL_CONNECTED) {
      ToggleLED
        delay(300);
        debug("o");
      if (tries++ > 30) {
        debugln("");
        debugln("Setting up Captive Portal by the name 'P1_setup'");
        LEDon
        WiFi.mode(WIFI_AP);
        softAp = WiFi.softAP("P1_Setup", "");
        APtimer = millis();
        breaking = true;
        break;
      }
     }    
      debugln("");
      debugln("Set up wifi, either in STA or AP mode");
    if (softAp){
        debugln("running in AP mode, all handles will be initiated");
      start_webservices();
    }

  if (WiFi.status() == WL_CONNECTED){ 
     WiFi.setAutoReconnect(true);
       debugln("HTTP server running.");
      debug("IP address: ");
       debugln(WiFi.localIP());
      setRFPower();
      wifiSta = true;
        debugln("wifi running in Sta (normal) mode");
      LEDoff
      ESP.rtcUserMemoryWrite(RTC_config_data_SLOT_WIFI_STATE, reinterpret_cast<uint32_t *>(&WiFistate), sizeof(WiFistate));
#ifdef SLEEP_ENABLED
      modemSleep();
      modemWake();
#else
      start_services();
#endif
     
      
 
 // handle Files
 debug("Mounting file system ... ");
      if (!FST.begin()) {
          debugln("FST mount failed");
          debug("Formatting file system ... "); 
          FST.format();
          if (!FST.begin()) {
            debugln("FST mount failed AGAIN");
          } else 
          { 
            debugln("done.");
            if (zapfiles) zapFiles();
          }
      } else debugln("done.");

     debugln("Reading logdata:");
      File logData = FST.open("/logData.txt", "r");
        if (logData) {
         logData.read((byte *)&log_data, sizeof(log_data)/sizeof(byte));
        logData.close();
        } else {
          debugln("Failed to open logData.txt for reading");
          needToInitLogVars = true;
          needToInitLogVarsGas = true;
        }
        if (zapfiles) zapFiles();
      
  } // WL connected
 //debugln("Something is terribly wrong, no network connection");
  timerAlarm.stopService();
  settimeofday_cb(timeIsSet_cb);
  configTime(MYTZ, "pool.ntp.org");

 debugln("All systems are go...");
  alignToTelegram();
  state = WAITING;    // signal that we are waiting for a valid start char (aka /)
  devicestate = CONFIG;
  nextUpdateTime = nextMQTTreconnectAttempt = EverSoOften = TenSecBeat = millis();
   
  monitoring = true; // start monitoring data
  time_to_sleep = millis() + wakeTime;  // we go to sleep wakeTime seconds from now  
  datagram.reserve(1500);
}

void readTelegram() {
  if (Serial.available()) {
    memset(telegram, 0, sizeof(telegram));
    while (Serial.available()) {
      int len = Serial.readBytesUntil('\n', telegram, MAXLINELENGTH);
      telegram[len] = '\n';
      telegram[len+1] = 0;
      yield();
      ToggleLED      
      if(decodeTelegram(len+1)){     // test for valid CRC
        debug2ln(datagram);
          break;
      } else { // we don't have valid data, but still may need to report to Domo
        if (dataEnd && !CRCcheckEnabled) { //this is used for dsmr 2.2 meters
         // yield(); //state = WAITING; 
        }
      }
    }
    LEDoff
  }
}

void loop() {  
  if ((millis() > nextUpdateTime)){ // && monitoring){
    if (!OEstate) { // OE is disabled  == false
       RTS_on();
       Serial.flush();
    }
  } // update window  
  if (OEstate) readTelegram();

#ifdef SLEEP_ENABLED
  if ((millis() > time_to_sleep) && !atsleep && wifiSta){  // not currently sleeping and sleeptime
    modemSleep();
  }
  if (wifiSta && (millis() > time_to_wake) && (WiFi.status() != WL_CONNECTED)) { // time to wake, if we're not already awake
     modemWake();
  }
#endif
  
  if (datagramValid && (state == DONE) && (WiFi.status() == WL_CONNECTED)){ 
      if (Mqtt) {
        doMQTT();
        if (MqttDelivered) {
           MqttDelivered = false;  // reset
        }
      }
      if (Json)       doJSON();
      if (Telnet)     TelnetReporter();
      if (MQTT_debug) MQTT_Debug();
      
      datagramValid = false;  // reset
      state = WAITING;
     }


  if (softAp || (WiFi.status() == WL_CONNECTED)) {
        server.handleClient(); //handle web requests
        MDNS.update();
  //      if (Telnet) telnetloop();// telnet.loop();
  }

if (millis() > TenSecBeat){
  if (Telnet && wifiSta) telnetloop();
  TenSecBeat = millis() + 10000;
}

if (millis() > EverSoOften){
    checkCounters();
    resetFlags();
    doWatchDogs();
    EverSoOften = millis() + 22000;
    
  }
  timerAlarm.update();
}   

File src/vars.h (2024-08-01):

#include <WString.h>

/*
 * vars.h
 */
struct settings {
  char dataSet[4];
  char ssid[32];
  char password[64];
  char domoticzIP[30] = "IPaddress";
  char domoticzPort[10] = "Port";
  char domoticzEnergyIdx[10] = "EnergyIdx";
  char domoticzGasIdx[10] = "GasIdx";
  char mqttTopic[50] = "sensors/power/p1meter";
  char mqttIP[30] = "";
  char mqttPort[10] = "";
  char mqttUser[32] = "";
  char mqttPass[64] = "";
  char interval[3] = "20";
  char domo[4] = "j";
  char mqtt[4] = "n";
  char watt[4] = "n";
  char telnet[4] = "n";
  char debug[4] = "n";
  char adminPassword[32];
} config_data = {};

// admin related
bool bootSetup = false; // flag for adminpassword bypass
bool AdminAuthenticated = false;
char setupToken[18];

// Value that is parsed as a three-decimal float, but stored as an
// integer (by multiplying by 1000). Supports val() (or implicit cast to
// float) to get the original value, and int_val() to get the more
// efficient integer value. The unit() and int_unit() methods on
// FixedField return the corresponding units for these values.
struct FixedValue {
  FixedValue() {
    _value = 0;
  }
  FixedValue(String value) {
    _value = value.toFloat() * 1000;
  }
  operator float() { return val(); }
  float val() { return _value / 1000.0; }
  uint32_t int_val() { return _value; }

  uint32_t _value{0};
};

// Vars to store meter readings
// we capture all data in char arrays or Strings for longer hard to delineate
// data
struct DSMRData {
  // String identification;
  String p1_version;                   // P1version
  String timestamp;                    // P1timestamp
  String equipment_id;                 // equipmentId
  FixedValue energy_delivered_tariff1; // electricityUsedTariff1
  FixedValue energy_delivered_tariff2; // electricityUsedTariff2
  FixedValue energy_returned_tariff1;  // electricityReturnedTariff1
  FixedValue energy_returned_tariff2;  // electricityReturnedTariff2
  String electricity_tariff;           // tariffIndicatorElectricity
  FixedValue power_delivered;          // actualElectricityPowerDeli
  FixedValue power_returned;           // actualElectricityPowerRet
  // FixedValue electricity_threshold;
  // uint8_t electricity_switch_position;
  uint32_t electricity_failures;      // numberPowerFailuresAny
  uint32_t electricity_long_failures; // numberLongPowerFailuresAny
  String electricity_failure_log;     // longPowerFailuresLog
  uint32_t electricity_sags_l1;       // numberVoltageSagsL1
  uint32_t electricity_sags_l2;       // numberVoltageSagsL2
  uint32_t electricity_sags_l3;       // numberVoltageSagsL3
  uint32_t electricity_swells_l1;     // numberVoltageSwellsL1
  uint32_t electricity_swells_l2;     // numberVoltageSwellsL2
  uint32_t electricity_swells_l3;     // numberVoltageSwellsL3
  // String message_short;
  // String message_long;
  FixedValue voltage_l1;         // instantaneousVoltageL1
  FixedValue voltage_l2;         // instantaneousVoltageL2
  FixedValue voltage_l3;         // instantaneousVoltageL3
  FixedValue current_l1;         // instantaneousCurrentL1
  FixedValue current_l2;         // instantaneousCurrentL2
  FixedValue current_l3;         // instantaneousCurrentL3
  FixedValue power_delivered_l1; // activePowerL1P
  FixedValue power_delivered_l2; // activePowerL2P
  FixedValue power_delivered_l3; // activePowerL3P
  FixedValue power_returned_l1;  // activePowerL1NP
  FixedValue power_returned_l2;  // activePowerL2NP
  FixedValue power_returned_l3;  // activePowerL3NP

  // uint16_t gas_device_type;
  String gas_equipment_id; // equipmentId2
  // uint8_t gas_valve_position;
  String gas_delivered; // gasReceived5min

  // uint16_t thermal_device_type;
  // String thermal_equipment_id;
  // uint8_t thermal_valve_position;
  // String thermal_delivered;

  // uint16_t water_device_type;
  // String water_equipment_id;
  // uint8_t water_valve_position;
  // String water_delivered;
  // uint16_t sub_device_type;
  // String sub_equipment_id;
  // uint8_t sub_valve_position;
  // String sub_delivered;

  uint8_t P1prot() { return p1_version[0] == '4' ? 4 : 5; }
} dsmrData;

String prevGAS; // not an P1 protocol var, but holds gas value

// logging vars
byte logFlags;
// #define secFlag    1
// #define minFlag    2
// #define hourFlag   4
// #define dayFlag    8
// #define weekFlag   16
// #define monthFlag  32
// #define yearFlag   64
bool timeIsSet = false;
bool TimeTriggersSet = false;

bool minFlag = false;
bool hourFlag = false;
bool dayFlag = false;
bool weekFlag = false;
bool monthFlag = false;
bool yearFlag = false;
unsigned long EverSoOften = 0;
unsigned long TenSecBeat = 0;
unsigned long FiveSecBeat = 0;
unsigned long SecBeat = 0;

#define SET_FLAG(n, f) n = n | f;  //((n) |= (f))
#define CLR_FLAG(n, f) n = n & !f; //((n) &= ~(f))
//#define TGL_FLAG(n, f) ((n) ^= (f))
#define CHK_FLAG(n, f) (n & f) //((n) & (f))

int checkMinute = 0; // holds when doHourly was called
char minG[12];

struct logvars {
  char hourE1[12]; // delivered tariff 1
  char hourE2[12]; // delivered tariff 2
  char hourR1[12]; // return tariff 1
  char hourR2[12]; // return tariff 2
  char hourTE[12]; // total tariff 1
  char hourTR[12]; // total tariff 2
  char hourG[12];  // Gas

  char dayE1[12];
  char dayE2[12];
  char dayR1[12];
  char dayR2[12];
  char dayTE[12];
  char dayTR[12];
  char dayG[12];

  char weekE1[12];
  char weekE2[12];
  char weekR1[12];
  char weekR2[12];
  char weekTE[12];
  char weekTR[12];
  char weekG[12];

  char monthE1[12];
  char monthE2[12];
  char monthR1[12];
  char monthR2[12];
  char monthTE[12];
  char monthTR[12];
  char monthG[12];

  char yearE1[12];
  char yearE2[12];
  char yearR1[12];
  char yearR2[12];
  char yearTE[12];
  char yearTR[12];
  char yearG[12];
} log_data = {};

// energy management vars
int interval;
unsigned long nextUpdateTime = 0;
unsigned long LastReportinMillis = 0;
unsigned long LastSample = 0;
time_t LastReportinSecs = 0;

long last10 = 0;
bool monitoring = false; // are we permitted to collect P1 data? Not if in setup
                         // or firmware update

// datagram stuff
#define MAXLINELENGTH                                                          \
  2048 // 0-0:96.13.0 has a maximum lenght of 1024 chars + 11 of its identifier
char telegram[MAXLINELENGTH]; // holds a single line of the datagram
String datagram;              // holds entire datagram for raw output
String meterId = "";
String meterName = "";
bool meternameSet = false; // do we have a metername already?

bool datagramValid = false; //
int dataFailureCount = 0; //counter for CRC failures
bool dataEnd = false; // signals that we have found the end char in the data (!)
unsigned int currentCRC = 0; // the CRC v alue of the datagram
bool gas22Flag = false; // flag for parsing second gas line on dsmr2.2 meters
bool reportInDecimals = true;
bool CRCcheckEnabled = true; // by default enable CRC checking
String mtopic = "Een lange MQTT boodschap als placeholder";
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

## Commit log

2022-07-26 initial commit
    public release van de firmware
2022-08-01 versie 1.0m
    m: setupsave fix, relocate to p1wifi.local na 60 sec
    * mqtt - kw/W fix
    [P1WG2022current.ino]
2022-08-02 small fix
    menu button in setup screen fix
2022-08-03 bugfixes
    fixed settings mess-up when calling SetupSave in browser, fixed kWh/Wh setting, fixed P1 reporting window
    [P1WG2022current.ino, decoder.ino]
2022-08-30 updates and fixes
    updates and fixes
    [P1WG2022current.ino, decoder.ino]
2022-10-23 lots of changes
    Localisations for Nederlands, German, Swedish.
    lots of small fixes. Still not done with start-up powermanagement.
    [P1WG2022current.ino, decoder.ino, webserverDE.ino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]
2022-11-18 Version 1.0t
    Many rewrites and bugfixes
    [JSON.ino, MQTT.ino, P1WG2022current.ino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]
2022-11-21 version 1.0ta
    telnet bugfix
    [P1WG2022current.ino]
2022-11-28 FR localisation and fixes
    [P1WG2022current.ino, webserverFR.ino, webserverSE.ino]
2023-01-01 version 1.0u updates
    Significant extra's and bugfixes.
    [JSON.ino, MQTT.ino, P1WG2022current.ino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]
2023-01-05 bugfixes u-> ua
    corrected writing wrongly sized parameters to EEPROM
    [P1WG2022current.ino, debug.ino, webserverNL.ino]
2023-01-23 v1.1: implemented local logging and graphs (and bugfixes)
    Meter data will now be logged on the module's LittleFS file system in hourly, daily (for a week, month and entire year) format. Logfiles can be downloaded and displayed in graphical form locally, so no need to hand over your meter data to a third party or run HA, Domoticz or similar to get an overview of your energy usage.
    [JSON.ino, MQTT.ino, P1WG2022current.ino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]
2023-02-13 logging features/graph extensions
    Logging finally seems to work continuously. Swedish version updated to include passwd on Setup/Update.
    [P1-wifi-gateway22v4jlc.kicad_pcb, P1-wifi-gateway22v4jlc.kicad_sch]
2023-03-15 bug fixes
    bug fixes
    [MQTT.ino, P1WG2022current.ino, decoder.ino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]
2023-11-15 small fixes
    version correction and debug version
    [P1WG_IDE_2.0.ino]
2024-02-16 Split LED and crc32 functions and other cleanups
2024-03-27 meter id fix
    Meter iD fix
    [main.cpp]
2024-05-11 Added platformio esp8285 board
2024-05-11 Several fixes + Added vscode settings file to gitignore
    [main.cpp]
2024-07-21 current Arduino build
    Huidge Arduino build. Deze versie loopt achter op de platformIO versie

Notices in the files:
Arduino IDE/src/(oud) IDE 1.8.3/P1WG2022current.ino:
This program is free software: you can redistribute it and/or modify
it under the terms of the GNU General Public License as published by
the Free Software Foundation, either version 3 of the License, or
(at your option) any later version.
